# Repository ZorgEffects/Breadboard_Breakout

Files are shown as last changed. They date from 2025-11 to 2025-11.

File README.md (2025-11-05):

# Breadboard_Breakout
This is a PCB of a breakout audio board used for audio design on a breadboard.  
It's been made to align with a 1660pt breadboard like this one:  
https://mou.sr/4qExcgZ

# Features:
- 9v regulator. Can be turned off with a jumper.
- 3x jacks in/out/aux for audio/CVs
- Relay bypass between IN/OUT. The relay can be removed with jumper.
- 4x push switches with wiring connection
- 6x screw connectors to fix pots on the boards and wire them to the breadboard
- Filtered Vref = Vcc/2
- Bananas connexion for an external power supply
- Test points for signals (T1 and T2, near the bananas)
- Test points for I/Os (IN/OUT/AUX, right of the jacks)

# Short BOM:
Relay :  
https://www.mouser.fr/ProductDetail/Omron-Electronics/G6K-2P-Y-DC9?qs=wkx8pu8tL7LXpnqEum69xQ%3D%3D  
Push Switch (latch):  
https://www.mouser.fr/ProductDetail/E-Switch/JN2UOANAGX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  
Switch cap:  
https://www.mouser.fr/ProductDetail/E-Switch/TAG-BLK?qs=sGAEpiMZZMtFyPk3yBMYYOwc5eDcStsDSmqEZ9eg82w%3D  
Pot connector:  
https://www.mouser.fr/ProductDetail/Phoenix-Contact/1935394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  
Bypass switch:  
https://www.mouser.fr/ProductDetail/Same-Sky/TS14-1212-100-BK-160-SCR-D?qs=t7xnP681wgUxNt1zer%2Bdww%3D%3D  
Jacks:  
https://www.mouser.fr/ProductDetail/Neutrik/NMJ4HCD2?qs=SzdD80gJ2cAr9Xh3wJi7nw%3D%3D  
Terminals 2.54:  
https://www.mouser.fr/ProductDetail/3M-Electronic-Solutions-Division/2324-6121TG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  
https://www.mouser.fr/c/connectors/headers-wire-housings/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  

The bananas plugs are these:  
https://www.microjpm.com/products/ad27504/

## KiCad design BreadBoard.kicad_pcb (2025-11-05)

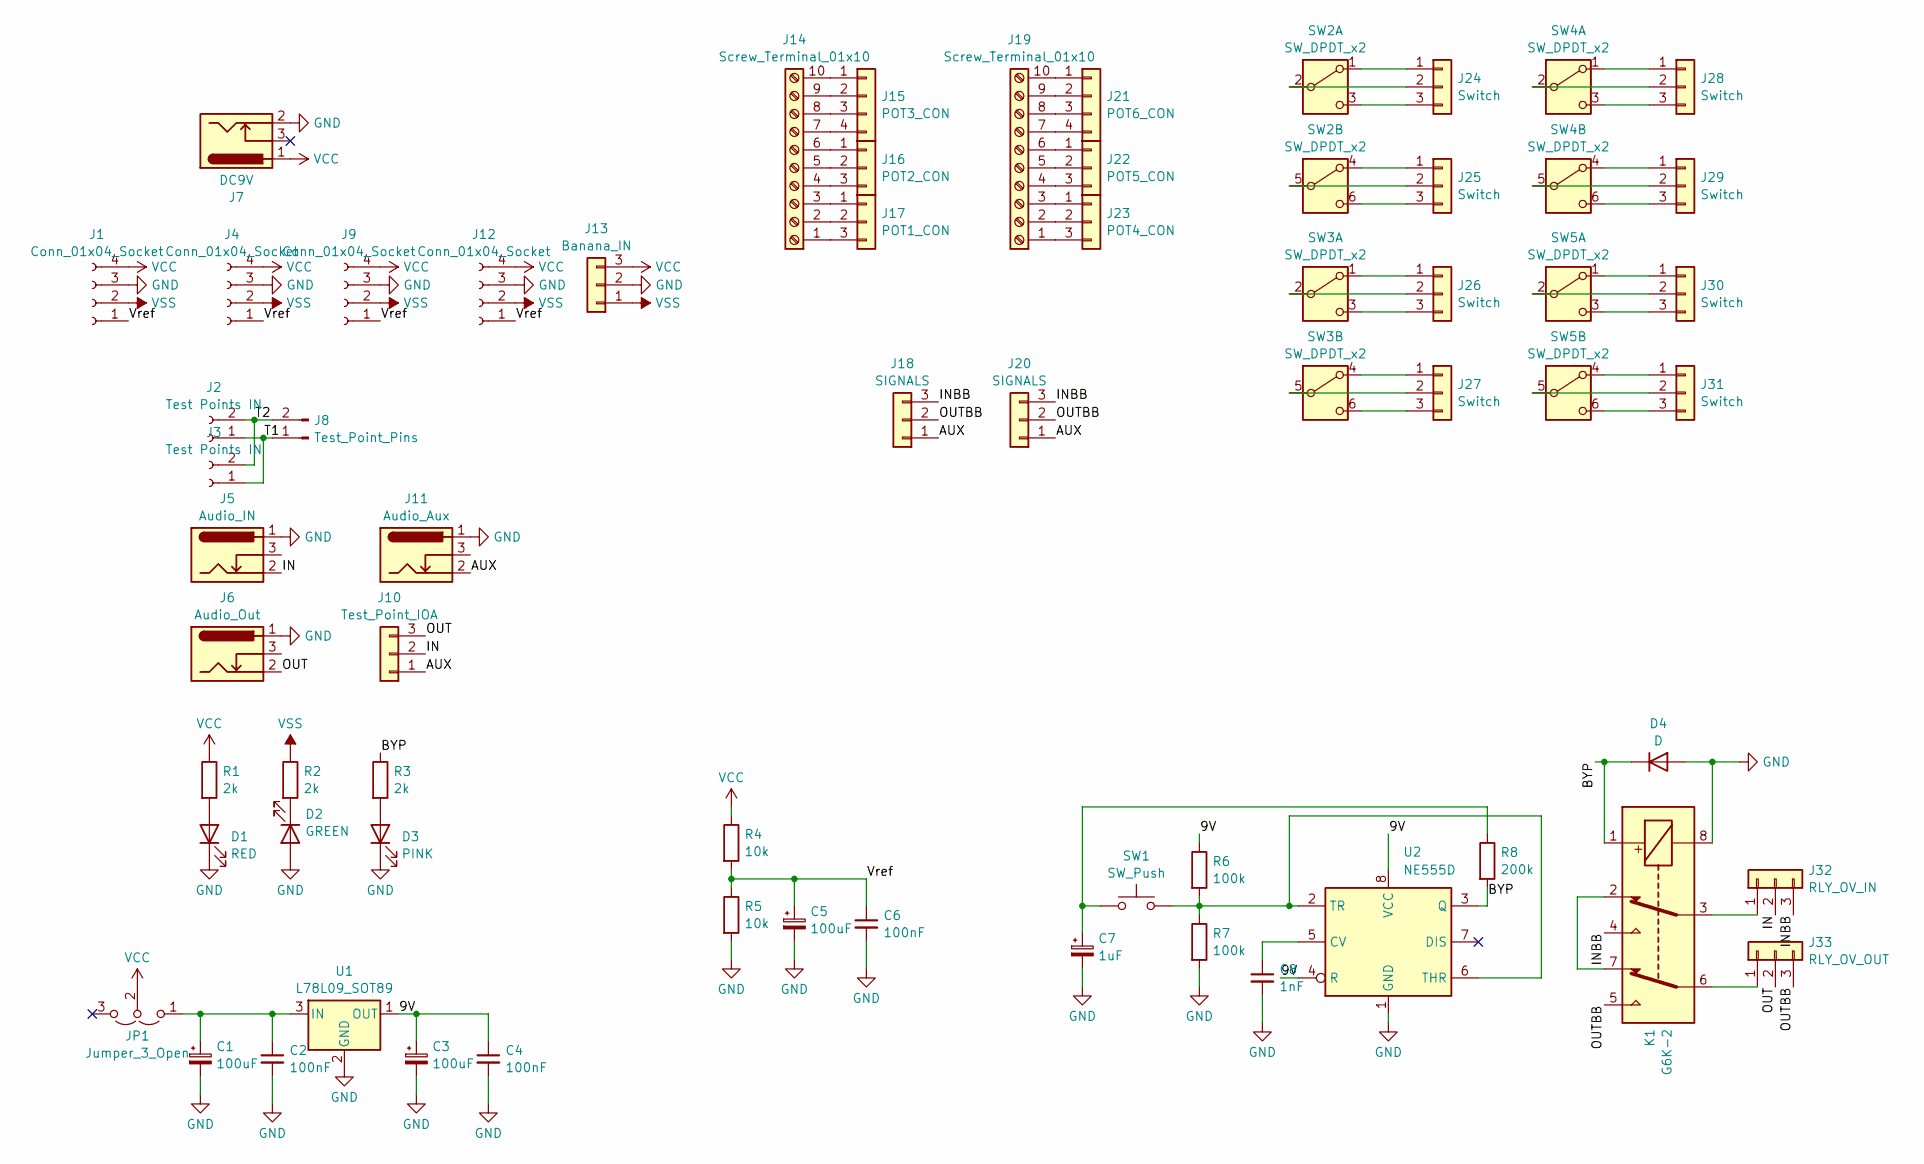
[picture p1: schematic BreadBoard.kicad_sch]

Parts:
C1, C3, C5: 100uF; CP_Radial_D6.3mm_P2.50mm
C2, C4, C6: 100nF; C_Rect_L7.0mm_W2.0mm_P5.00mm
C7: 1uF; CP_Radial_D4.0mm_P2.00mm
C8: 1nF; C_Rect_L7.0mm_W2.0mm_P5.00mm
D1: RED; LED_D5.0mm
D2: GREEN; LED_D5.0mm
D3: PINK; LED_D5.0mm
D4: D; D_A-405_P7.62mm_Horizontal
J1, J4, J9, J12: Conn_01x04_Socket; PinSocket_1x04_P2.54mm_Vertical
J2, J3: Test Points IN; PinSocket_1x02_P2.54mm_Vertical
J5: Audio_IN; Jack Neutrik Mono Pins SW
J6: Audio_Out; Jack Neutrik Mono Pins SW
J7: DC9V; Jack DC
J8: Test_Point_Pins; PinHeader_1x02_P2.54mm_Vertical
J10: Test_Point_IOA; PinHeader_1x03_P2.54mm_Vertical
J11: Audio_Aux; Jack Neutrik Mono Pins SW
J13: Banana_IN; PinHeader_1x03_P2.54mm_Vertical
J14, J19: Screw_Terminal_01x10; TerminalBlock_RND_205-00020_1x10_P5.00mm_Horizontal
J15: POT3_CON; PinSocket_1x04_P2.54mm_Vertical
J16: POT2_CON; PinSocket_1x03_P2.54mm_Vertical
J17: POT1_CON; PinSocket_1x03_P2.54mm_Vertical
J18, J20: SIGNALS; PinSocket_1x03_P2.54mm_Vertical
J21: POT6_CON; PinSocket_1x04_P2.54mm_Vertical
J22: POT5_CON; PinSocket_1x03_P2.54mm_Vertical
J23: POT4_CON; PinSocket_1x03_P2.54mm_Vertical
J24, J25, J26, J27, J28, J29, J30, J31: Switch; PinSocket_1x03_P2.54mm_Vertical
J32: RLY_OV_IN; PinHeader_1x03_P2.54mm_Vertical
J33: RLY_OV_OUT; PinHeader_1x03_P2.54mm_Vertical
JP1: Jumper_3_Open; PinHeader_1x03_P2.54mm_Vertical
K1: G6K-2; Relay_DPDT_Omron_G6K-2P-Y
R1, R2, R3: 2k; R_Axial_DIN0207_L6.3mm_D2.5mm_P10.16mm_Horizontal
R4, R5: 10k; R_Axial_DIN0207_L6.3mm_D2.5mm_P10.16mm_Horizontal
R6, R7: 100k; R_Axial_DIN0207_L6.3mm_D2.5mm_P10.16mm_Horizontal
R8: 200k; R_Axial_DIN0207_L6.3mm_D2.5mm_P10.16mm_Horizontal
SW1: SW_Push; SW_PUSH-12mm
SW2, SW3, SW4, SW5: SW_DPDT_x2; DPDT_ESwitch
U1: L78L09_SOT89; DPAK-3
U2: NE555D; SOIC-8_3.9x4.9mm_P1.27mm

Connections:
/9V: C3.1, C4.1, R6.1, U1.1 (OUT), U2.4 (R), U2.8 (VCC)
/AUX: J10.1, J11.2, J18.1, J20.1
/BYP: D4.1 (K), K1.1, R3.1, R8.2, U2.3 (Q)
/IN: J5.2, J10.2, J32.2
/INBB: J18.3, J20.3, J32.3, K1.4
/OUT: J6.2, J10.3, J33.2
/OUTBB: J18.2, J20.2, J33.3, K1.5
/T1: J2.1, J3.1, J8.1
/T2: J2.2, J3.2, J8.2
/Vref: C5.1, C6.1, J1.1, J4.1, J9.1, J12.1, R4.2, R5.1
GND: C1.2, C2.2, C3.2, C4.2, C5.2, C6.2, C7.2, C8.2, D1.1 (K), D2.2 (A), D3.1 (K), D4.2 (A), J1.3, J4.3, J5.1, J6.1, J7.2, J9.3, J11.1, J12.3, J13.2, K1.8, R5.2, R7.2, U1.2 (GND), U2.1 (GND)
unnamed: C7.1, R8.1, SW1.1
unnamed: D1.2 (A), R1.2
unnamed: D2.1 (K), R2.2
unnamed: D3.2 (A), R3.2
unnamed: J14.1, J17.3
unnamed: J14.2, J17.2
unnamed: J14.3, J17.1
unnamed: J14.4, J16.3
unnamed: J14.5, J16.2
unnamed: J14.6, J16.1
unnamed: J14.7, J15.4
unnamed: J14.8, J15.3
unnamed: J14.9, J15.2
unnamed: J14.10, J15.1
unnamed: J19.1, J23.3
unnamed: J19.2, J23.2
unnamed: J19.3, J23.1
unnamed: J19.4, J22.3
unnamed: J19.5, J22.2
unnamed: J19.6, J22.1
unnamed: J19.7, J21.4
unnamed: J19.8, J21.3
unnamed: J19.9, J21.2
unnamed: J19.10, J21.1
unnamed: J24.1, SW2.1 (A)
unnamed: J24.2, SW2.2 (B)
unnamed: J24.3, SW2.3 (C)
unnamed: J25.1, SW2.4 (A)
unnamed: J25.2, SW2.5 (B)
unnamed: J25.3, SW2.6 (C)
unnamed: J26.1, SW3.1 (A)
unnamed: J26.2, SW3.2 (B)
unnamed: J26.3, SW3.3 (C)
unnamed: J27.1, SW3.4 (A)
unnamed: J27.2, SW3.5 (B)
unnamed: J27.3, SW3.6 (C)
unnamed: J28.1, SW4.1 (A)
unnamed: J28.2, SW4.2 (B)
unnamed: J28.3, SW4.3 (C)
unnamed: J29.1, SW4.4 (A)
unnamed: J29.2, SW4.5 (B)
unnamed: J29.3, SW4.6 (C)
unnamed: J30.1, SW5.1 (A)
unnamed: J30.2, SW5.2 (B)
unnamed: J30.3, SW5.3 (C)
unnamed: J31.1, SW5.4 (A)
unnamed: J31.2, SW5.5 (B)
unnamed: J31.3, SW5.6 (C)
unnamed: J32.1, K1.3
unnamed: J33.1, K1.6
unnamed: C1.1, C2.1, JP1.1 (A), U1.3 (IN)
unnamed: K1.2, K1.7
unnamed: C8.1, U2.5 (CV)
unnamed: R6.2, R7.1, SW1.2, U2.2 (TR), U2.6 (THR)
VCC: J1.4, J4.4, J7.1, J9.4, J12.4, J13.3, JP1.2 (C), R1.1, R4.1
VSS: J1.2, J4.2, J9.2, J12.2, J13.1, R2.1

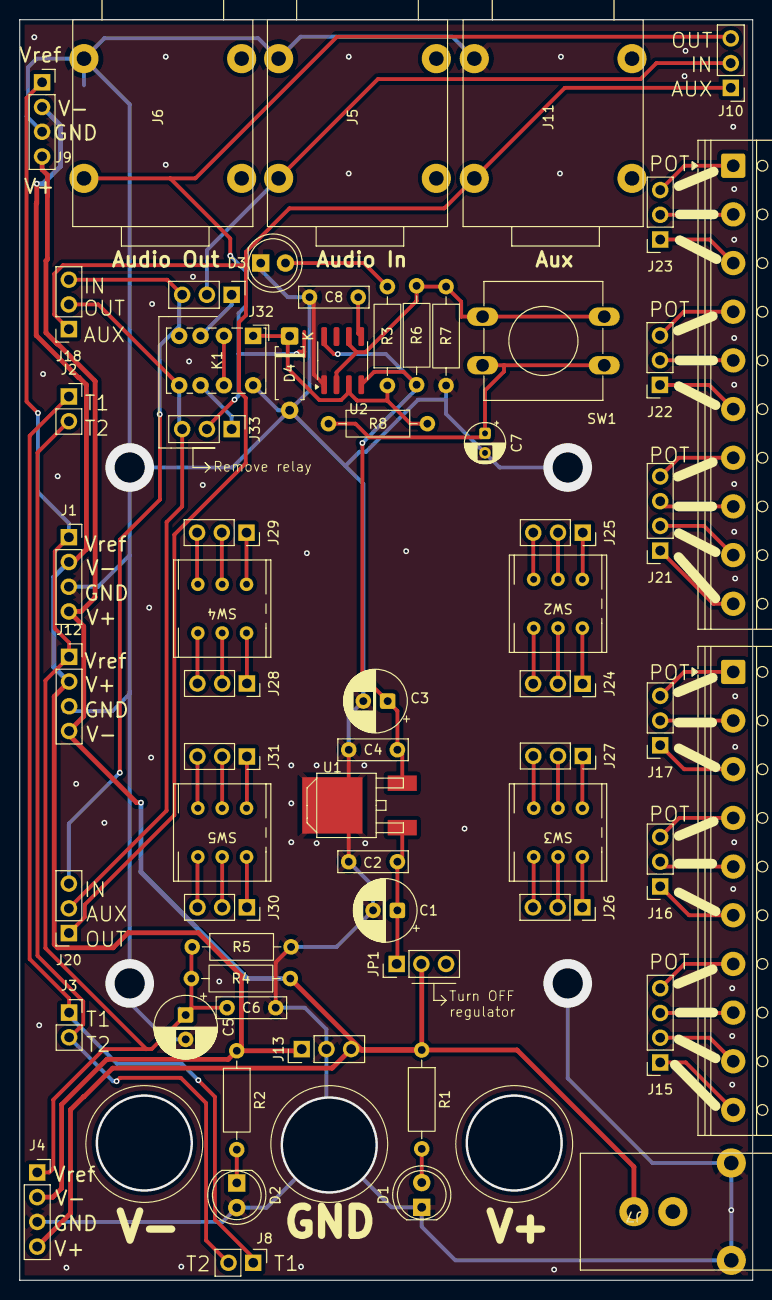
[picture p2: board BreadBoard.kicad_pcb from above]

Board: 2 copper layers, 75.3 x 129.5 mm, 62 parts (0 on the bottom side), 67 nets.
